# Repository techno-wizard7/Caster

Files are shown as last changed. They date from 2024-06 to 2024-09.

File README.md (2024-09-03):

# Caster
Smartwatch-esqe remote controller and communicator

This device is made to be in many ways, an arduino-based custom wrist mounted version of the Flipper-Zero with built-in LoRa, with a few key differences TBD in development. Additionally there will be a default loRa messaging app, based on Bobricus's [Armachat](https://github.com/bobricius/armachat). 

This project is still deep in alpha, and is subject to change rapidly. Contributions not accepted at this time.

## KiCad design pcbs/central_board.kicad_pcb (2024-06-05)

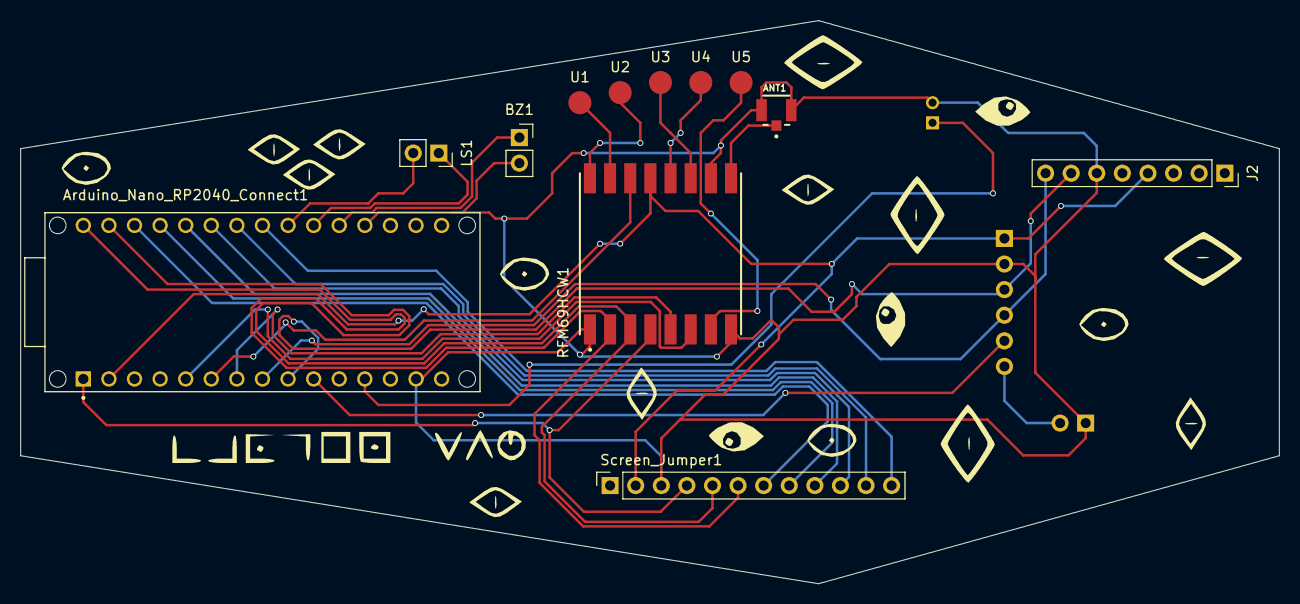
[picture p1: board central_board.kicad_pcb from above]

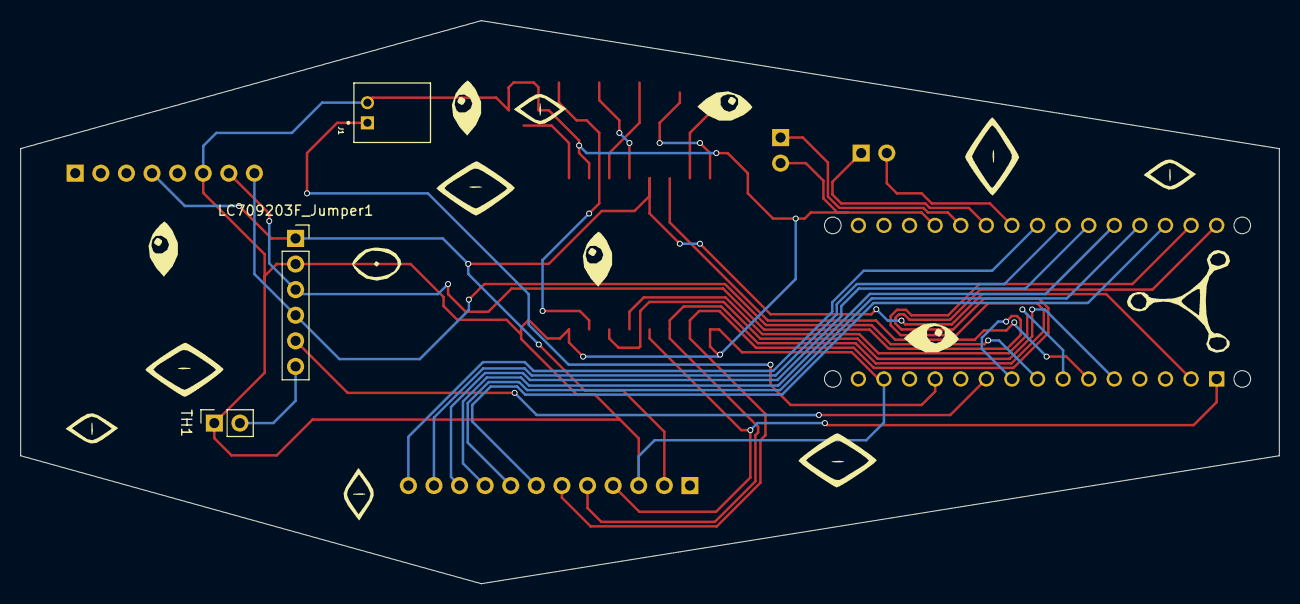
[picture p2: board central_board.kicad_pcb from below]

Board: 2 copper layers, 124.9 x 55.9 mm, 15 parts (3 on the bottom side), 23 nets.

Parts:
ANT1: RSP-122811-01; SAMTEC_RSP-122811-01
Arduino_Nano_RP2040_Connect1: ABX00053; MODULE_ABX00053
BZ1: Buzzer; PinSocket_1x02_P2.54mm_Vertical
J1: S2B-PH-K-S(LF)(SN); JST_S2B-PH-K-S(LF)(SN)
J2: Conn_01x08_Male; PinSocket_1x08_P2.54mm_Vertical
LC709203F_Jumper1: Conn_01x06; PinSocket_1x06_P2.54mm_Vertical
LS1: Speaker; PinSocket_1x02_P2.54mm_Vertical
RFM69HCW1: COM-13909; MOD_COM-13909
Screen_Jumper1: Conn_01x12; PinSocket_1x12_P2.54mm_Vertical
TH1: Thermistor; PinSocket_1x02_P2.54mm_Vertical
U1, U2, U3, U4, U5: Single_Jumper; JUMPERPAD

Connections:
+3V3: Arduino_Nano_RP2040_Connect1.2 (+3V3), J2.4, LC709203F_Jumper1.1, RFM69HCW1.13 (3.3V), Screen_Jumper1.2
AUD_OUT: Arduino_Nano_RP2040_Connect1.22 (D4/GPIO26), LS1.2
Aud_IN: Arduino_Nano_RP2040_Connect1.21 (D3/GPIO15), LS1.1
BUZZ: Arduino_Nano_RP2040_Connect1.20 (D2/GPIO25), BZ1.1 (-)
Bat_INT: Arduino_Nano_RP2040_Connect1.10 (A6), LC709203F_Jumper1.5
CIPO: Arduino_Nano_RP2040_Connect1.30 (D12/GPIO4/CIPO), RFM69HCW1.2 (MISO), Screen_Jumper1.6
COPI: Arduino_Nano_RP2040_Connect1.29 (D11/GPIO7/COPI), RFM69HCW1.3 (MOSI), Screen_Jumper1.5
DC: Arduino_Nano_RP2040_Connect1.26 (D8/GPIO20), Screen_Jumper1.9
GND: ANT1.G1, ANT1.G2, Arduino_Nano_RP2040_Connect1.14 (GND), Arduino_Nano_RP2040_Connect1.19 (GND), BZ1.2 (+), J1.2, J2.6, LC709203F_Jumper1.2, RFM69HCW1.1 (GND), RFM69HCW1.8 (GND), RFM69HCW1.10 (GND), Screen_Jumper1.3, TH1.1
LORA_CS: Arduino_Nano_RP2040_Connect1.7 (A3/GPIO29), RFM69HCW1.5 (NSS)
LORA_INT: Arduino_Nano_RP2040_Connect1.6 (A2/GPIO28), RFM69HCW1.14 (DIO0)
Lite: Arduino_Nano_RP2040_Connect1.24 (D6/GPIO18), Screen_Jumper1.11
Lora_RST: Arduino_Nano_RP2040_Connect1.5 (A1/GPIO27), RFM69HCW1.6 (RESET)
unnamed: ANT1.1, RFM69HCW1.9 (ANT)
unnamed: Arduino_Nano_RP2040_Connect1.12 (+5V), J1.1
unnamed: LC709203F_Jumper1.6, TH1.2
RST: Arduino_Nano_RP2040_Connect1.27 (D9/GPIO21), Screen_Jumper1.8
SCK: Arduino_Nano_RP2040_Connect1.1 (D13/GPIO6), RFM69HCW1.4 (SCK), Screen_Jumper1.4
SCL: Arduino_Nano_RP2040_Connect1.9 (A5/GPIO13), J2.7, LC709203F_Jumper1.3
SDA: Arduino_Nano_RP2040_Connect1.8 (A4/GPIO12), J2.8, LC709203F_Jumper1.4
SDCS: Arduino_Nano_RP2040_Connect1.25 (D7/GPIO19), Screen_Jumper1.10
TE: Arduino_Nano_RP2040_Connect1.23 (D5/GPIO17), Screen_Jumper1.12
TFTCS: Arduino_Nano_RP2040_Connect1.28 (D10/GPIO5), Screen_Jumper1.7

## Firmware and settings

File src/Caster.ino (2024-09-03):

#define SerialPort Serial
#include <Adafruit_GFX.h>
#include <Adafruit_SPITFT.h>
#include <Adafruit_SPITFT_Macros.h>
// #include "lib/QuickContextMenu/src/Menu.h"
#include "Menu.h"
#include "display.h"
#include <Adafruit_ST7789.h>
#include <SPI.h>

#ifdef TARGET_RP2040
#include "mbed.h"
#include "Kernel.h"
#include <Scheduler.h> // Include Scheduler since we want to manage multiple tasks.
#include "WiFiNINA.h"
#include <LSM6DSOSensor.h>
// On Nano RP2040 Connect, RGB leds are connected to the wifi module
// The user APIs are the same, but we can't convert to int, so use defines

#define led1  LEDR
#define led2  LEDG
#define led3  LEDB
// #define DEV_I2C Wire
#endif
#include "controller.h"
// #include <Arduino_GFX_Library.h> //Faster than Adafruit and better primatives, but uncooperative with Nano Connect

#define TFT_CS 9 // GFX_NOT_DEFINED for display without CS pin
#define TFT_DC 8
#define TFT_RST 7
#define TFT_BACKLIGHT  6 // Display backlight pin

// #define LCDTFT
#ifdef LCDTFT// For when/if Arduino_GFX_Library adds support to ArduinoCore-Mbed (Depending on time/resources I may just port a custom fork that can handle the RP2040. Or adapt code to function on multiple target hardware configurations)
  // // 1.5" square IPS LCD 240x240
  Arduino_DataBus *bus = new Arduino_HWSPI(TFT_DC, TFT_CS);//, 18 /* SCK */, 23 /* MOSI */, spi0 /* MISO */);
  Arduino_GFX *output_display = new Arduino_ST7789(bus, TFT_RST, 0 /* rotation */, true /* IPS */, 240 /* width */, 240 /* height */, 0 /* col offset 1 */, 0 /* row offset 1 */, 0 /* col offset 2 */, 80 /* row offset 2 */);
  Arduino_GFX *canvas = new Arduino_Canvas(240 /* width */, 240 /* height */, output_display);
#else
  Adafruit_ST7789* output_display = new  Adafruit_ST7789(TFT_CS, TFT_DC, TFT_RST);
  GFXcanvas16 *canvas = new GFXcanvas16(240, 240); // 16-bit, 120x30 pixels
#endif
  bool isDisplayVisible = false;

// #define GAMEPAD
#ifdef GAMEPAD
#define BUTTON_X         6
#define BUTTON_Y         2
#define BUTTON_A         5
#define BUTTON_B         1
#define BUTTON_SELECT    0
#define BUTTON_START    16
#define JOY_X    14
#define JOY_Y    15
GamepadController pad;
#else

SerialController pad;
#endif
LSM6DSOSensor accGyr(&Wire);
volatile int mems_event = 0;
void INT1Event_cb();
unsigned long previousMillis;
long idleTime = 10000;

//clock functions (need to be stored better, but the code is borrowed to test if it works)
#define SIXTIETH 0.016666667
#define TWELFTH 0.08333333
#define SIXTIETH_RADIAN 0.10471976
#define TWELFTH_RADIAN 0.52359878
#define RIGHT_ANGLE_RADIAN 1.5707963

static uint8_t conv2d(const char *p)
{
  uint8_t v = 0;
  return (10 * (*p - '0')) + (*++p - '0');
}
static int16_t hh, mm, ss;
static unsigned long targetTime; // next action time



Menu* rootMenu(new Menu("Root Menu"));
//#define IRQ_PIN   5
void setup() {
  // boot priorities
  Serial.begin(115200);
  pinMode(TFT_BACKLIGHT, OUTPUT);
  digitalWrite(TFT_BACKLIGHT, LOW);
  Wire.begin();	  // I2C
  output_display->init(240, 240);
  output_display->enableDisplay(isDisplayVisible);
  canvas->fillScreen(0x00);
  // display.drawBitmap(0, 0, canvas.getBuffer(),canvas.width(), canvas.height(), 0xFFFF, 0x0000);     
  // if (!gfx->begin())
  // // if (!gfx->begin(80000000)) /* specify data bus speed */
  // {
  //   Serial.println("gfx->begin() failed!");
  // }

  //SD
  //ReadSettings
  toggleDisplay();
  //periphrials

  pad.begin();

  hh = conv2d(__TIME__);
  mm = conv2d(__TIME__ + 3);
  ss = conv2d(__TIME__ + 6);

  targetTime = ((millis() / 1000) + 1) * 1000;

  //Start Sensors

  //LSM6DSOX IMU
  attachInterrupt(A3, INT1Event_cb, RISING);
  // Initlialize components.
  accGyr.begin();
  accGyr.Enable_X();
  // Enable Wake Up Detection.
  accGyr.Enable_Wake_Up_Detection(LSM6DSO_INT1_PIN);

  //connect wireless nets
    Scheduler.startLoop(controllerLoop);

}



void loop() {
  //OG loop will handle base functions, data accumulation, task manager, and managing the root menu. There's also the base watch face.
  unsigned long cur_millis = millis();
  if (cur_millis >= targetTime)
  {
    targetTime += 1000;
    ss++; // Advance second
    if (ss == 60)
    {
      ss = 0;
      mm++; // Advance minute
      if (mm > 59)
      {
        mm = 0;
        hh++; // Advance hour
        if (hh > 23)
        {
          hh = 0;
        }
      }
    }
  }
  
  if(isDisplayVisible)
    checkIdle();
  else
    checkWakeEvent();
  char ** buffer;
  size_t bufferSize = snprintf(NULL, 0, "%d:%d:%d", hh, mm, ss) + 1;
  *buffer = (char*)malloc(bufferSize);
  snprintf(*buffer, bufferSize, "%d:%d:%d", hh, mm, ss);
  defaultWatchFace(canvas, 1, buffer);

}

void controllerLoop() {
  //check controller and save state in global for other functions
  //will be seperate thread to reduce lag on
  pad.update();
 
}

void wirelessListener() {

}

void displayWrite(){
  if(isDisplayVisible)
    output_display->drawRGBBitmap(0, 0, canvas->getBuffer(),canvas->width(), canvas->height());
  // display.drawRGBBitmap(0, 0, canvas.getBuffer(),canvas.width(), canvas.height());
}

void toggleDisplay(){
  isDisplayVisible = !isDisplayVisible;
  output_display->enableDisplay(isDisplayVisible);
  digitalWrite(TFT_BACKLIGHT, HIGH & isDisplayVisible); // Backlight on
  #if (SerialDebugging)
  Serial.print("button pressed @ ");
  Serial.print(millis());
  Serial.print(", display is now ");
  Serial.println((isDisplayVisible ? "ON" : "OFF"));
  #endif
}

void checkIdle(){
  if(isDisplayVisible && ((millis() - previousMillis) > idleTime))
    toggleDisplay();
}

void checkWakeEvent(){
  if (mems_event && !isDisplayVisible) {
    mems_event = 0;
    LSM6DSO_Event_Status_t status;
    accGyr.Get_X_Event_Status(&status);
    if (status.WakeUpStatus)
    {
      toggleDisplay();
      previousMillis = millis();
      SerialPort.println("Wake up Detected!");
      return;
    }
  }
  if(pad.change() && !isDisplayVisible)
    toggleDisplay();
}

void INT1Event_cb()
{
  mems_event = 1;
}
/*core screens
-Watch 1 (casual)
-watch 2 (hud)
-Quick select(two levels or more (to implement later))
-"load" program
-settings menu
-quick select assigners
-comms menu
*/

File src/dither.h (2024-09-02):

#ifndef dither
#define dither
#include <Adafruit_GFX.h>

#ifndef _swap_int16_t
#define _swap_int16_t(a, b)                                                    \
  {                                                                            \
    int16_t t = a;                                                             \
    a = b;                                                                     \
    b = t;                                                                     \
  }
#endif


/* Piskel data for "DitherMap" */

// black and white

const uint8_t epd_bitmapBayer_matrix_dithering1 [] PROGMEM = {
	0x00, 0x00, 0x00, 0x00
};
const uint8_t epd_bitmapBayer_matrix_dithering2 [] PROGMEM = {
	0x80, 0x00, 0x00, 0x00
};
// 'Bayer_matrix_dithering2', 4x4px
const uint8_t epd_bitmapBayer_matrix_dithering3 [] PROGMEM = {
	0x80, 0x00, 0x20, 0x00
};
// 'Bayer_matrix_dithering3', 4x4px
const uint8_t epd_bitmapBayer_matrix_dithering4 [] PROGMEM = {
	0x80, 0x00, 0xa0, 0x00
};
// 'Bayer_matrix_dithering4', 4x4px
const uint8_t epd_bitmapBayer_matrix_dithering5 [] PROGMEM = {
	0xa0, 0x00, 0xa0, 0x00
};
// 'Bayer_matrix_dithering5', 4x4px
const uint8_t epd_bitmapBayer_matrix_dithering6 [] PROGMEM = {
	0xa0, 0x40, 0xa0, 0x00
};
// 'Bayer_matrix_dithering6', 4x4px
const uint8_t epd_bitmapBayer_matrix_dithering7 [] PROGMEM = {
	0xa0, 0x40, 0xa0, 0x10
};
// 'Bayer_matrix_dithering7', 4x4px
const uint8_t epd_bitmapBayer_matrix_dithering8 [] PROGMEM = {
	0xa0, 0x40, 0xa0, 0x50
};
// 'Bayer_matrix_dithering8', 4x4px
const uint8_t epd_bitmapBayer_matrix_dithering9 [] PROGMEM = {
	0xa0, 0x50, 0xa0, 0x50
};

// Array of all bitmaps for convenience. (Total bytes used to store images in PROGMEM = 256)
const int epd_bitmapallArray_LEN = 8;
const uint8_t* dithering[] = {
	epd_bitmapBayer_matrix_dithering9,
	epd_bitmapBayer_matrix_dithering8,
	epd_bitmapBayer_matrix_dithering7,
	epd_bitmapBayer_matrix_dithering6,
	epd_bitmapBayer_matrix_dithering5,
	epd_bitmapBayer_matrix_dithering4,
	epd_bitmapBayer_matrix_dithering3,
	epd_bitmapBayer_matrix_dithering2,
  epd_bitmapBayer_matrix_dithering1
};

// Helper function to get a pixel from the old bitmap stored in PROGMEM
bool getPixel(const uint8_t* bitmap, int width, int x, int y) {
    int byteWidth = (width + 7) / 8;  // Width of the image in bytes
    uint8_t byte = pgm_read_byte(&bitmap[y * byteWidth + x / 8]);
    return (byte & (0x80 >> (x % 8))) != 0;
}

// Helper function to set a pixel in the new bitmap
void setPixel(uint8_t* bitmap, int width, int x, int y, bool color) {
    int byteWidth = (width + 7) / 8;  // Width of the image in bytes
    if (color) {
        bitmap[y * byteWidth + x / 8] |= (0x80 >> (x % 8));
    } else {
        bitmap[y * byteWidth + x / 8] &= ~(0x80 >> (x % 8));
    }
}

uint8_t* resizeBitmap(const uint8_t* oldBitmap, int oldWidth, int oldHeight, int newWidth, int newHeight) {
    // Allocate memory for the new bitmap
    int newByteWidth = (newWidth + 7) / 8;
    uint8_t* newBitmap = new uint8_t[newHeight * newByteWidth];
    memset(newBitmap, 0, newHeight * newByteWidth);  // Initialize new bitmap to 0 (black)

    // Calculate scaling factors
    float xScale = (float)oldWidth / newWidth;
    float yScale = (float)oldHeight / newHeight;

    // Iterate over each pixel in the new bitmap
    for (int newY = 0; newY < newHeight; newY++) {
        for (int newX = 0; newX < newWidth; newX++) {
            // Find the corresponding pixel in the old bitmap using nearest-neighbor scaling
            int oldX = (int)(newX * xScale);
            int oldY = (int)(newY * yScale);

            // Get the pixel value from the old bitmap stored in PROGMEM and set it in the new bitmap
            bool color = getPixel(oldBitmap, oldWidth, oldX, oldY);
            setPixel(newBitmap, newWidth, newX, newY, color);
        }
    }

    return newBitmap;
}

uint8_t* getDitherFrame(int density, int w, int h){
  if (density < 0)
    density = 0;
  else if (density > 8)
    density = 8;
  return resizeBitmap(dithering[density], 4, 4, w, h);
}

void printDithertest2(Adafruit_GFX* display, int a){
  for(int i = 0; i < display->width(); i=i+64){
    for(int j = 0; j < display->height(); j=j+64){
      uint8_t* newBitmap = resizeBitmap(dithering[a], 4, 4, 64, 64);
      display->drawBitmap(i, j, newBitmap, 64, 64, ST77XX_BLUE, ST77XX_CYAN);
      delete[] newBitmap;
    }
  }
}

void printDithertest(Adafruit_GFX* display, int a){
  for(int i = 0; i < display->width(); i=i+32){
    for(int j = 0; j < display->height(); j=j+32){
      display->drawBitmap(i, j, dithering[a], 4, 4, 0xffff, 0x0000);
    }
  }
}


void writeDitherLine(Adafruit_GFX* display, int16_t x0, int16_t y0, int16_t x1, int16_t y1, int w, int h, int density, uint16_t color1, uint16_t color2) {
  if (density < 0) {
    _swap_int16_t(color1, color2);
    density *=-1;
  }
  uint8_t* ditherFrame = getDitherFrame(density, w, h);
  int16_t steep = abs(y1 - y0) > abs(x1 - x0);
  if (steep) {
    _swap_int16_t(x0, y0);
    _swap_int16_t(x1, y1);
  }

  if (x0 > x1) {
    _swap_int16_t(x0, x1);
    _swap_int16_t(y0, y1);
  }

  int16_t dx, dy;
  dx = x1 - x0;
  dy = abs(y1 - y0);

  int16_t err = dx / 2;
  int16_t ystep = h;

  if (y0 < y1) {
    ystep *= 1;
  } else {
    ystep *= -1;
  }

  for (; x0 <= x1; x0 += w) {
    if (steep) {
      display->drawBitmap(y0, x0, ditherFrame, w, h, color1, color2);
    } else {
      display->drawBitmap(x0, y0, ditherFrame, w, h, color1, color2);
    }
    err -= dy;
    if (err < 0) {
      y0 += ystep;
      err += dx;
    }
  }
  delete[] ditherFrame;
}

void drawFastHDitherLine(Adafruit_GFX* display, int16_t x, int16_t y, int16_t width, int16_t h, int16_t w, int16_t density, uint16_t color1, uint16_t color2) {
  writeDitherLine(display, x, y, x + width - 1, y, h, w, density, color1, color2);
}

void drawFastVDitherLine(Adafruit_GFX* display, int16_t x, int16_t y, int16_t width, int16_t h, int16_t w, int16_t density, uint16_t color1, uint16_t color2) {
  writeDitherLine(display, x, y, x, y + width - 1, h, w, density, color1, color2);
}

uint16_t interpolateColor(uint16_t color1, uint16_t color2, float ratio) {
    uint8_t r1 = (color1 >> 11) & 0x1F;  // Extract red component from color1
    uint8_t g1 = (color1 >> 5) & 0x3F;   // Extract green component from color1
    uint8_t b1 = color1 & 0x1F;          // Extract blue component from color1
    
    uint8_t r2 = (color2 >> 11) & 0x1F;  // Extract red component from color2
    uint8_t g2 = (color2 >> 5) & 0x3F;   // Extract green component from color2
    uint8_t b2 = color2 & 0x1F;          // Extract blue component from color2
    
    // Interpolate red, green, and blue components
    uint8_t r = r1 + (r2 - r1) * ratio;
    uint8_t g = g1 + (g2 - g1) * ratio;
    uint8_t b = b1 + (b2 - b1) * ratio;
    
    // Combine interpolated components back into a 16-bit color value
    return (r << 11) | (g << 5) | b;
}
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

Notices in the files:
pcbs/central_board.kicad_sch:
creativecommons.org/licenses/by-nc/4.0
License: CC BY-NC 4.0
